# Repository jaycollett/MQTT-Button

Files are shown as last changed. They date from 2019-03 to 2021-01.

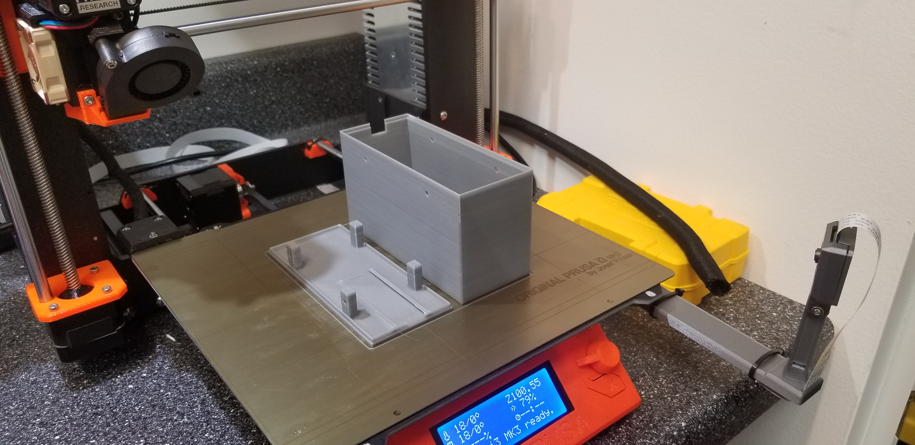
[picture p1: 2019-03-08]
Project Images/20190223_083257.jpg

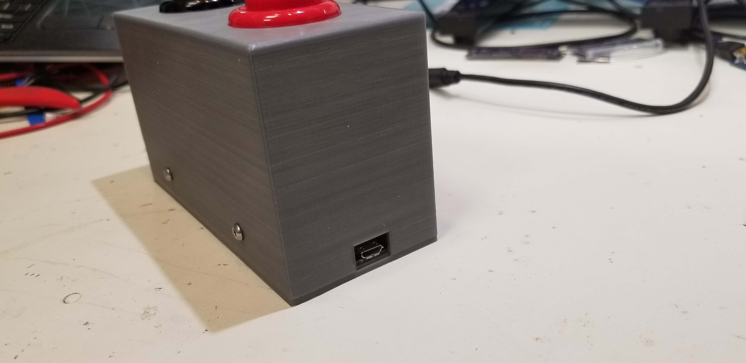
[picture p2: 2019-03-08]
Project Images/20190308_104535.jpg

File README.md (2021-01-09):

# MQTT-Button
 

Simple MQTT based dual button device. For all the details on this project, head over to my blog. 

https://www.jaycollett.com/2019/03/a-simple-dual-mqtt-button/

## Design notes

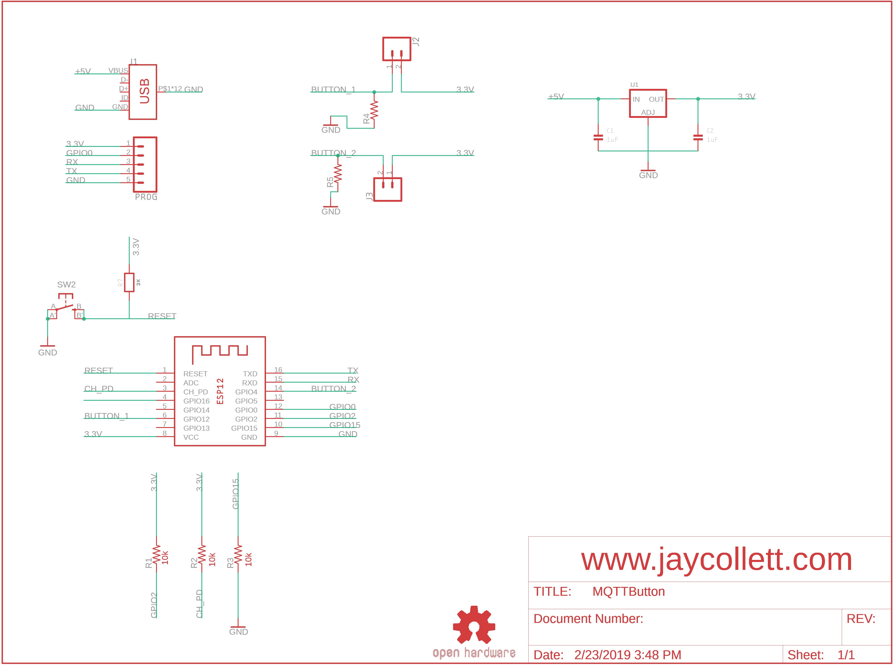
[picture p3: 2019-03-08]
EagleCAD/Schematic.png

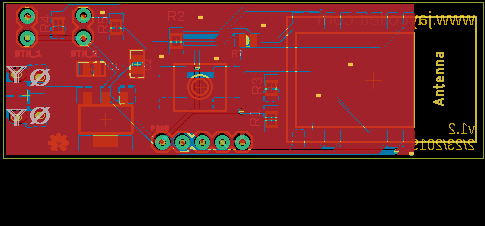
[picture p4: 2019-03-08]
EagleCAD/Board.png

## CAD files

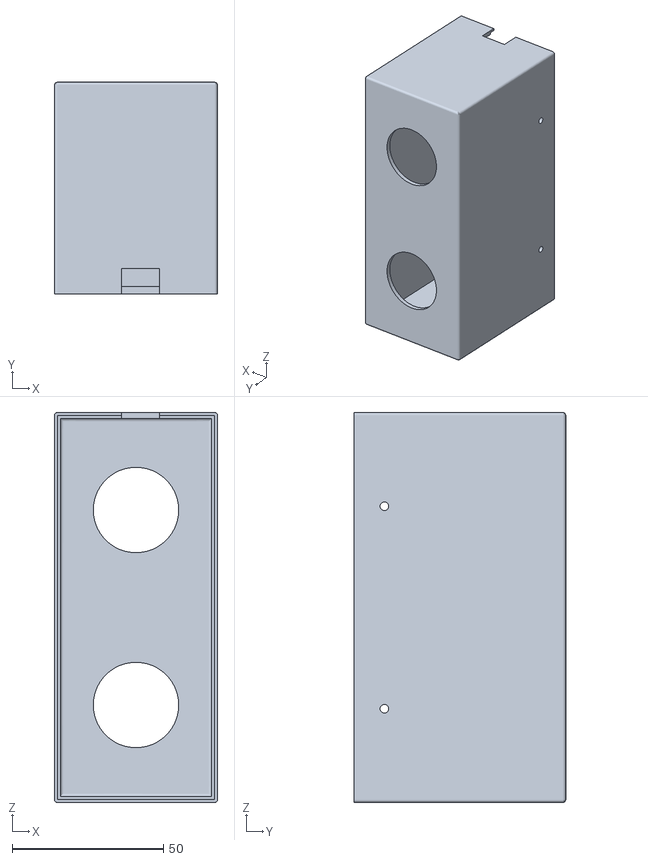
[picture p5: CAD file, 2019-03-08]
Project Enclosure/Top.stl
54.0 x 70.0 x 129.0

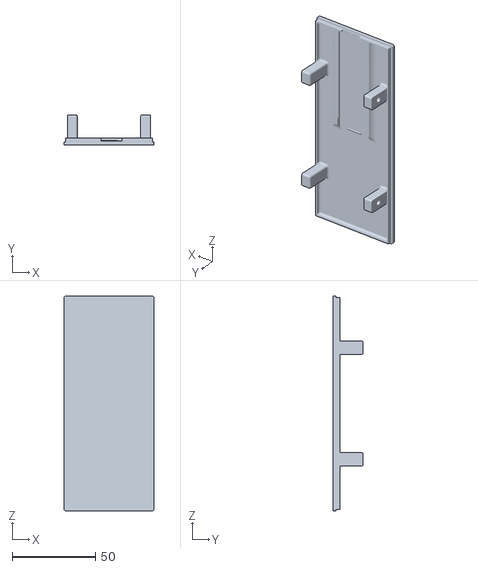
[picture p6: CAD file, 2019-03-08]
Project Enclosure/Bottom.stl
54.0 x 18.3 x 129.0

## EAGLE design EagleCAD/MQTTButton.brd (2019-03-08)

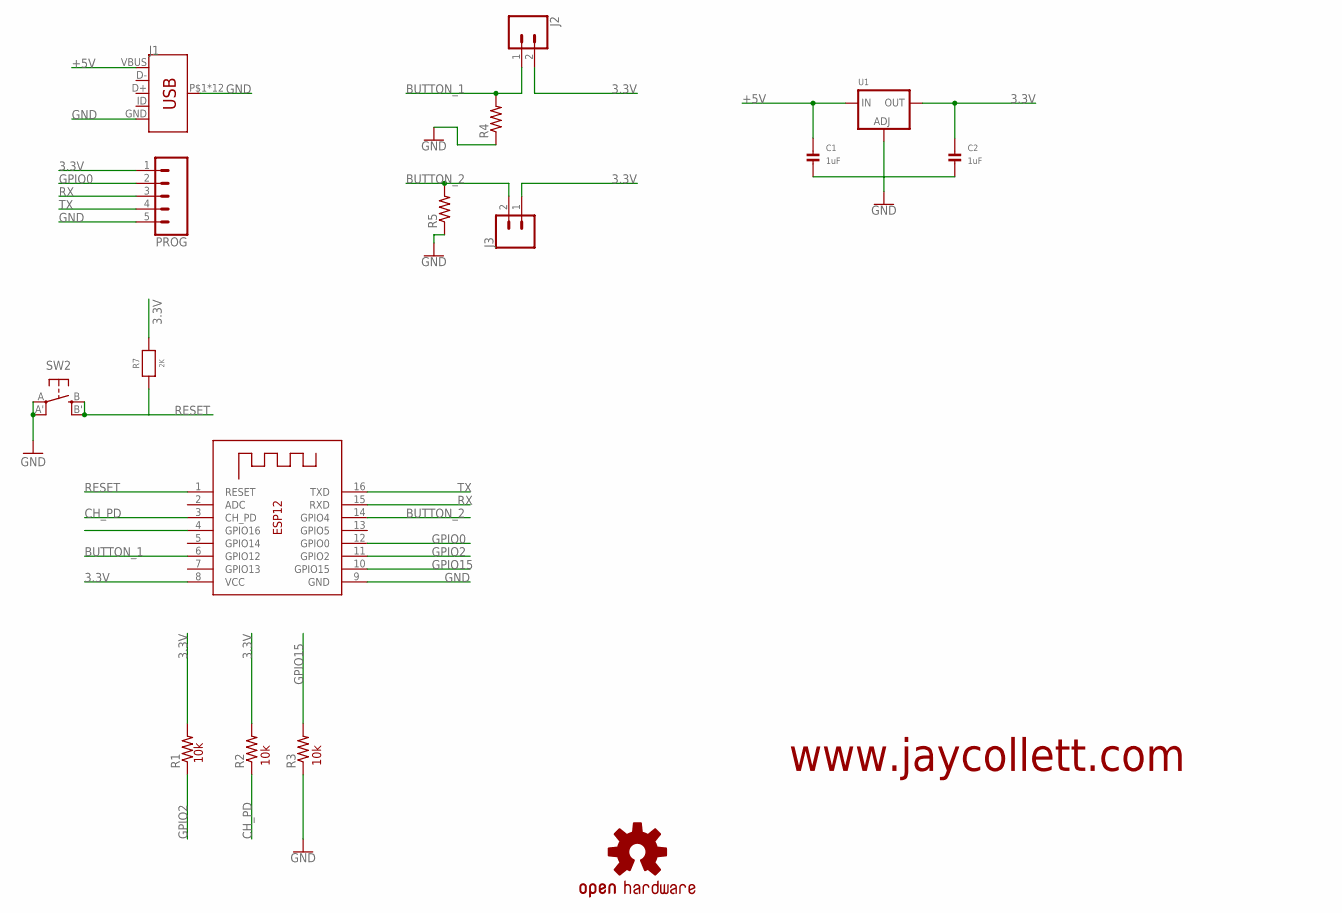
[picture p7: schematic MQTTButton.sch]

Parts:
C1, C2: 1uF; 0805
J1: USB_MICRO-B_HALF_PTH; USB-MICROB-PTH
J2, J3: CONN_02LOCK; 1X02_LOCK
LOGO1: OSHW-LOGOMINI; OSHW-LOGO-MINI
PROG: CONN_05; 1X05
R1, R2, R3, R4, R5: 10k; M0805
R7: 2K; 0805-NO
SW2: SPST_TACT-EVQQ2; EVQ-Q2
U1: LM1117SOT223-WAVE; SOT223-W
X1: ESP-12

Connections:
3.3V: C2.1, J2.2, J3.1, PROG.1, R1.2, R2.2, R7.2, U1.2 (OUT), X1.8 (VCC)
+5V: C1.1, J1.VBUS, U1.3 (IN)
BUTTON_1: J2.1, R4.2, X1.6 (GPIO12)
BUTTON_2: J3.2, R5.2, X1.14 (GPIO4)
CH_PD: R2.1, X1.3 (CH_PD)
GND: C1.2, C2.2, J1.GND, J1.P$1 (SHIELD), J1.P$2 (SHIELD), J1.P$3 (SHIELD), J1.P$4 (SHIELD), J1.P$6 (SHIELD), J1.P$8 (SHIELD), J1.P$10 (SHIELD), J1.P$12 (SHIELD), J1.SHEILD2 (SHIELD), J1.SHIELD, J1.SHIELD3 (SHIELD), J1.SHIELD4 (SHIELD), PROG.5, R3.1, R4.1, R5.1, SW2.A, SW2.A' (P1), U1.1 (ADJ), X1.9 (GND)
GPIO0: PROG.2, X1.12 (GPIO0)
GPIO2: R1.1, X1.11 (GPIO2)
GPIO15: R3.2, X1.10 (GPIO15)
RESET: R7.1, SW2.B (S), SW2.B' (S1), X1.1 (RESET)
RX: PROG.3, X1.15 (RXD)
TX: PROG.4, X1.16 (TXD)

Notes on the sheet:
10k
www.jaycollett.com

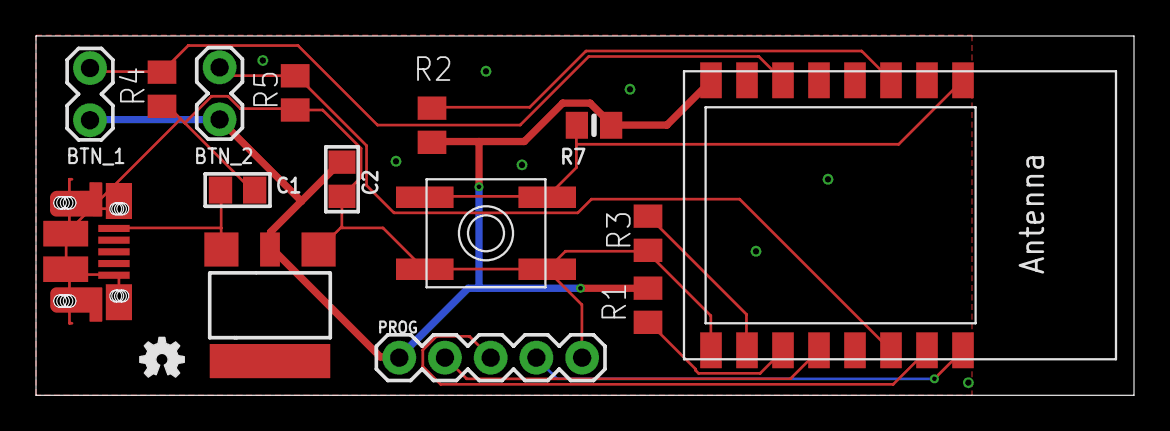
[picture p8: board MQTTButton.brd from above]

Board: 2 copper layers, 61.0 x 20.0 mm, 16 parts (0 on the bottom side), 12 nets.

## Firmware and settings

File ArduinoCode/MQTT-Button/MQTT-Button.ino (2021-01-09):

/**********************************************************************************************
  MQTT Button
  Written by: Jay Collett jay AT gmail.com
  Description:

  Sketch includes unmodified code libraries from the following awesome sources:
      PubSubClient  https://github.com/knolleary/pubsubclient
      ESP8266WiFi   https://github.com/esp8266/Arduino
 ***********************************************************************************************/
#include <ESP8266WiFi.h>
#include <PubSubClient.h>


#define phyButton1 12
#define phyButton2 5

#define WIFI_SSID "xxxxxxx"
#define WIFI_PASS "xxxxxxxxx"
#define MQTT_PORT 1883

int   wifiRetryCount = 0;
char  fmversion[7] = "v1.0";                  // firmware version
char  mqtt_server[] = "192.168.0.x";          // MQTT broker IP address
char  mqtt_username[] = "mqttLabButton";      // username for MQTT broker (USE ONE)
char  mqtt_password[] = "xxxxxxxxxxxxx";      // password for MQTT broker
char  mqtt_clientid[] = "mqttLabButton";      // client id for connections to MQTT broker

bool buttonOneOn = false;
bool buttonTwoOn = false;

const String HOSTNAME  = "mqttLabButton";
const String baseTopic = "mqttLabButton";
const String buttonOneTopic = baseTopic + "/" + "button1";
const String buttonTwoTopic = baseTopic + "/" + "button2";

IPAddress ip;
WiFiClient WiFiClient;
PubSubClient mqttclient(WiFiClient);

ADC_MODE(ADC_VCC);

void setup() {
  pinMode(phyButton1, INPUT);
  pinMode(phyButton2, INPUT);

  Serial.begin(115200);

  WiFi.hostname(HOSTNAME);
  WiFi.mode(WIFI_STA);

  mqttclient.setServer(mqtt_server, MQTT_PORT);

  WiFi.begin(WIFI_SSID, WIFI_PASS);
  while (WiFi.status() != WL_CONNECTED) {
    delay(250);
    Serial.print(".");
    if (wifiRetryCount >= 120) { // 250mS delay x 120 iterations = 30 seconds
      ESP.restart();
    }
    wifiRetryCount++;
  }

  wifiRetryCount = 0;

  Serial.println("");
  Serial.println("WiFi connected");
  Serial.print("IP address: ");
  Serial.println(WiFi.localIP());

  Serial.println("Calling MQTT Connect");
  MQTT_connect(); // connect to wifi/mqtt as needed
}

void loop() {

   MQTT_connect(); // connect to wifi/mqtt as needed

  // loop indefinitely, checking to see if someone has hit the doorbell button
  // doorbell sense pin will go HIGH if the doorbell button is being pushed
  if (digitalRead(phyButton1) == HIGH) {
    delay(150); // poor man's debounce
    if (digitalRead(phyButton1) == HIGH) {
      Serial.println("Somone hit button 1, send the MQTT message");
      // toggle on/off based on state of button
      if(buttonOneOn){
        mqttclient.publish(buttonOneTopic.c_str(), "OFF");
        buttonOneOn = false;
        Serial.println("Sent OFF payload for button 1");
      }else{
        mqttclient.publish(buttonOneTopic.c_str(), "ON");
        buttonOneOn = true;
        Serial.println("Sent ON payload for button 1");
      }
      delay(1000); // give time for the payload to register
    }
  }

  if (digitalRead(phyButton2) == HIGH) {
    delay(150); // poor man's debounce
    if (digitalRead(phyButton2) == HIGH) {
      Serial.println("Somone hit button 2, send the MQTT message");
      // toggle on/off based on state of button
      if(buttonTwoOn){
        mqttclient.publish(buttonTwoTopic.c_str(), "OFF");
        buttonTwoOn = false;
        Serial.println("Sent OFF payload for button 2");
      }else{
        mqttclient.publish(buttonTwoTopic.c_str(), "ON");
        buttonTwoOn = true;
        Serial.println("Sent ON payload for button 2");
      }
      delay(1000); // give time for the payload to register
    }
  }

}


// #############################################################################
//  mqtt Connect function
//  This function connects and reconnects as necessary to the MQTT server and
//  WiFi.
//  Should be called in the loop to ensure connectivity
// #############################################################################
void MQTT_connect() {
  int8_t ret;

  // Stop if already connected.
  if (mqttclient.connected()) {
    return;
  }

  Serial.print("Connecting to MQTT... ");

  // Loop until we're reconnected
  while (!mqttclient.connected()) {
    Serial.print("Attempting MQTT connection...");
    // Attempt to connect
    if (mqttclient.connect(mqtt_clientid, mqtt_username, mqtt_password)) {
      Serial.println("connected");
    } else {
      Serial.print("failed, rc=");
      Serial.print(mqttclient.state());
      Serial.println(" try again in 2 seconds");
      // Wait 2 seconds before retrying
      delay(2000);
    }
  }

  Serial.println("MQTT Connected!");
}

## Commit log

2019-02-12 Initial board layout and schematic. Sent to OSHPark.com
    [MQTTButton.brd, MQTTButton.sch]
2019-02-19 inital draft design for bottom of enclosure
    [Bottom.stl]
2019-02-19 tweaks to bottom
    [Bottom.stl]
2019-02-22 added top of enclosure, tweaked bottom to add screw hole supports
    [Bottom.stl, Top.stl]
2019-02-23 added additional mount towers to bottom, wasn't happen with how it was secured.
    [Bottom.stl, Top.stl]
2019-02-23 updated design to include pull-down resistors on button input lines
    [MQTTButton.brd, MQTTButton.sch]
2019-02-23 added updated images for schematic and board
2019-02-24 tweaking bottom board holder after getting PCBs.
    [Bottom.stl]
2019-02-24 tweaked top based on tweaks to bottom.
    [Top.stl]
2019-02-24 fixed usb connector, rerouted
    [MQTTButton.brd, MQTTButton.sch]
2019-02-24 tweaked location of board stopper tab
    [Bottom.stl]
2019-03-08 swapped button values
2021-01-09 Update MQTT-Button.ino
    remove unused callback code.

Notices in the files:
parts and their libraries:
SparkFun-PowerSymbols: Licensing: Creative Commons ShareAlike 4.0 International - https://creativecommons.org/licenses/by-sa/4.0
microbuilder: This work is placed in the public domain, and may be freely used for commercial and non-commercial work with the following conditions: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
